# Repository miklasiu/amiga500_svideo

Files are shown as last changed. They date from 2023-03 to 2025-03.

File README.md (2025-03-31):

I've just made it - there are errors :) I'll update sometime when I find the time. Generally it works. Basically red and blue are swapped on the AD724 input (oops) and input resistor divider needs to be adjusted to increase voltage a bit. Also AD724 input resistors need to have larger values to decrease current draw.

# amiga500_svideo
 Luma Chroma output from A500

GGLabs A520HD redraw with AD724 based SVIDEO.

Connector PCB to fit on the right side behind the floppy.

To keep the video port operational I will do high impedance input (not 75 ohm) tap directly to video hybrid circuit and adjust input level via resistor divider. 
The same applies to AD724. It needs 714mVpp so I _think_ it needs 1/2nd of the A500HD output. But we shall see.

Work in progress.

BTW - I just bought my 1st Amiga in 2022. So I am ~30years behind. Catching up. 
Just noticed all mods cost more than A500. It seems cheaper and surely funnier to do them myself.
Fortunately my A500 is broken so more projects coming as original parts are expensive too :D

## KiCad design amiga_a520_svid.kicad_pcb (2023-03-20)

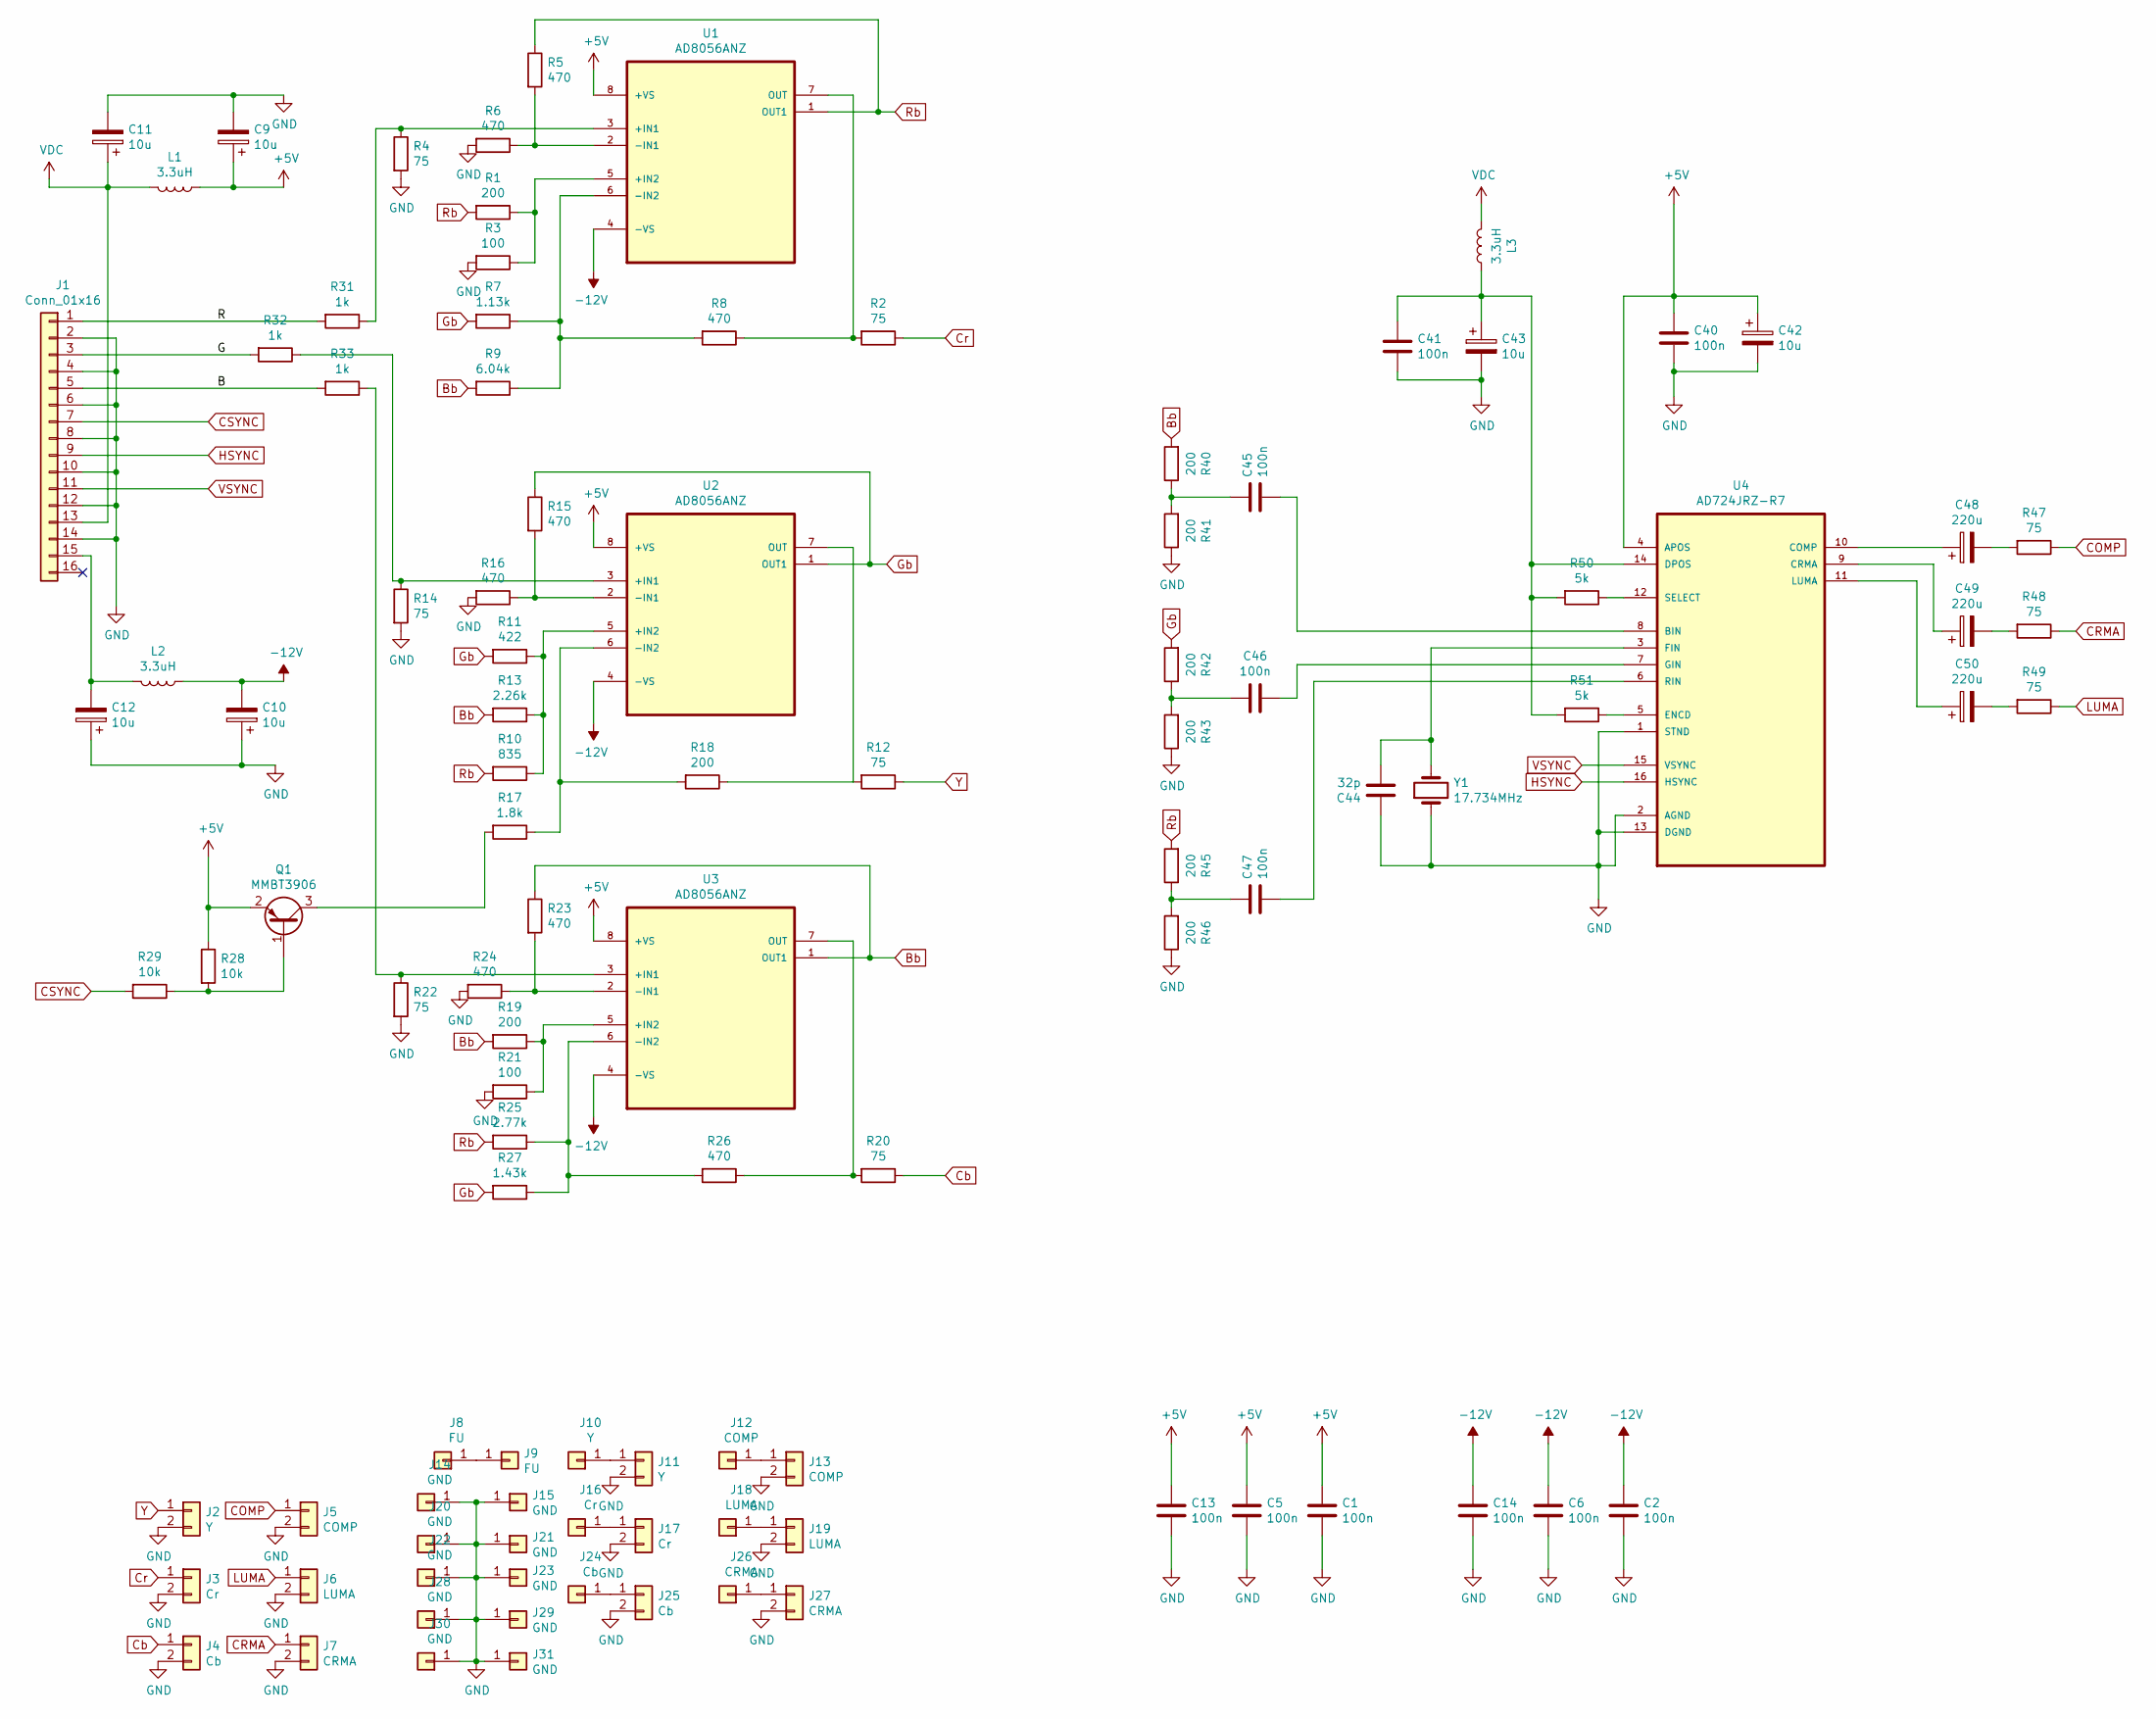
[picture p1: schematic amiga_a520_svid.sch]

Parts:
C1, C2, C5, C6, C13, C14, C40, C41, C45, C46, C47: 100n; C_1206_3216Metric_Pad1.33x1.80mm_HandSolder
C9, C10, C11, C12, C42, C43: 10u; CP_Elec_5x5.4
C44: 32p; C_1206_3216Metric_Pad1.33x1.80mm_HandSolder
C48, C49, C50: 220u; CP_Elec_6.3x7.7
J1: Conn_01x16; PinHeader_1x16_P1.27mm_Vertical_SMD_Pin1Left
J2, J11: Y; PinHeader_1x02_P2.54mm_Vertical
J3, J17: Cr; PinHeader_1x02_P2.54mm_Vertical
J4, J25: Cb; PinHeader_1x02_P2.54mm_Vertical
J5, J13: COMP; PinHeader_1x02_P2.54mm_Vertical
J6, J19: LUMA; PinHeader_1x02_P2.54mm_Vertical
J7, J27: CRMA; PinHeader_1x02_P2.54mm_Vertical
J8, J9: FU; Pin_D0.9mm_L10.0mm_W2.4mm_FlatFork
J10: Y; Pin_D0.9mm_L10.0mm_W2.4mm_FlatFork
J12: COMP; Pin_D0.9mm_L10.0mm_W2.4mm_FlatFork
J14, J15, J20, J21, J22, J23, J28, J29, J30, J31: GND; Pin_D0.9mm_L10.0mm_W2.4mm_FlatFork
J16: Cr; Pin_D0.9mm_L10.0mm_W2.4mm_FlatFork
J18: LUMA; Pin_D0.9mm_L10.0mm_W2.4mm_FlatFork
J24: Cb; Pin_D0.9mm_L10.0mm_W2.4mm_FlatFork
J26: CRMA; Pin_D0.9mm_L10.0mm_W2.4mm_FlatFork
L1, L2, L3: 3.3uH; L_Axial_L7.0mm_D3.3mm_P10.16mm_Horizontal_Fastron_MICC
Q1: MMBT3906; SOT-23
R1, R18, R19, R40, R41, R42, R43, R45, R46: 200; R_1206_3216Metric_Pad1.30x1.75mm_HandSolder
R2, R4, R12, R14, R20, R22, R47, R48, R49: 75; R_1206_3216Metric_Pad1.30x1.75mm_HandSolder
R3, R21: 100; R_1206_3216Metric_Pad1.30x1.75mm_HandSolder
R5, R6, R8, R15, R16, R23, R24, R26: 470; R_1206_3216Metric_Pad1.30x1.75mm_HandSolder
R7: 1.13k; R_1206_3216Metric_Pad1.30x1.75mm_HandSolder
R9: 6.04k; R_1206_3216Metric_Pad1.30x1.75mm_HandSolder
R10: 835; R_1206_3216Metric_Pad1.30x1.75mm_HandSolder
R11: 422; R_1206_3216Metric_Pad1.30x1.75mm_HandSolder
R13: 2.26k; R_1206_3216Metric_Pad1.30x1.75mm_HandSolder
R17: 1.8k; R_1206_3216Metric_Pad1.30x1.75mm_HandSolder
R25: 2.77k; R_1206_3216Metric_Pad1.30x1.75mm_HandSolder
R27: 1.43k; R_1206_3216Metric_Pad1.30x1.75mm_HandSolder
R28, R29: 10k; R_1206_3216Metric_Pad1.30x1.75mm_HandSolder
R31, R32, R33: 1k; R_1206_3216Metric_Pad1.30x1.75mm_HandSolder
R50, R51: 5k; R_1206_3216Metric_Pad1.30x1.75mm_HandSolder
U1, U2, U3: AD8056ANZ; DIP-8_W7.62mm_SOIC-8; MPN AD8056ANZ
U4: AD724JRZ-R7; SOIC-16W_7.5x10.3mm_P1.27mm; MPN AD724JRZ-R7
Y1: 17.734MHz; Resonator-2Pin_W10.0mm_H5.0mm

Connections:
+5V: C1.1, C5.1, C9.1, C13.1, C40.1, C42.1, L1.1, Q1.2 (E), R28.1, U1.8 (+VS), U2.8 (+VS), U3.8 (+VS), U4.4 (APOS)
-12V: C2.1, C6.1, C10.2, C14.1, L2.1, U1.4 (-VS), U2.4 (-VS), U3.4 (-VS)
/B: J1.5, R33.2
/G: J1.3, R32.2
/R: J1.1, R31.2
Bb: R9.2, R13.2, R19.2, R23.1, R40.2, U3.1 (OUT1)
COMP: J5.1, R47.1
CRMA: J7.1, R48.1
CSYNC: J1.7, R29.2
Cb: J4.1, R20.1
Cr: J3.1, R2.1
GND: C1.2, C2.2, C5.2, C6.2, C9.2, C10.1, C11.2, C12.1, C13.2, C14.2, C40.2, C41.2, C42.2, C43.2, C44.1, J1.2, J1.4, J1.6, J1.8, J1.10, J1.12, J1.14, J2.2, J3.2, J4.2, J5.2, J6.2, J7.2, J11.2, J13.2, J14.1, J15.1, J17.2, J19.2, J20.1, J21.1, J22.1, J23.1, J25.2, J27.2, J28.1, J29.1, J30.1, J31.1, R3.2, R4.2, R6.2, R14.2, R16.2, R21.2, R22.2, R24.2, R41.1, R43.1, R46.1, U4.1 (STND), U4.2 (AGND), U4.13 (DGND), Y1.1
Gb: R7.2, R11.2, R15.1, R27.2, R42.2, U2.1 (OUT1)
HSYNC: J1.9, U4.16 (HSYNC)
LUMA: J6.1, R49.1
unnamed: C12.2, J1.15, L2.2
unnamed: C41.1, C43.1, L3.1, R50.2, R51.2, U4.14 (DPOS)
unnamed: C44.2, U4.3 (FIN), Y1.2
unnamed: C45.1, R40.1, R41.2
unnamed: C45.2, U4.8 (BIN)
unnamed: C46.1, R42.1, R43.2
unnamed: C46.2, U4.7 (GIN)
unnamed: C47.1, R45.1, R46.2
unnamed: C47.2, U4.6 (RIN)
unnamed: C48.1, U4.10 (COMP)
unnamed: C48.2, R47.2
unnamed: C49.1, U4.9 (CRMA)
unnamed: C49.2, R48.2
unnamed: C50.1, U4.11 (LUMA)
unnamed: C50.2, R49.2
unnamed: J8.1, J9.1
unnamed: J10.1, J11.1
unnamed: J12.1, J13.1
unnamed: J16.1, J17.1
unnamed: J18.1, J19.1
unnamed: J24.1, J25.1
unnamed: J26.1, J27.1
unnamed: Q1.1 (B), R28.2, R29.1
unnamed: Q1.3 (C), R17.2
unnamed: R1.1, R3.1, U1.5 (+IN2)
unnamed: R2.2, R8.1, U1.7 (OUT)
unnamed: R5.2, R6.1, U1.2 (-IN1)
unnamed: R7.1, R8.2, R9.1, U1.6 (-IN2)
unnamed: R10.1, R11.1, R13.1, U2.5 (+IN2)
unnamed: R12.2, R18.1, U2.7 (OUT)
unnamed: R14.1, R32.1, U2.3 (+IN1)
unnamed: R15.2, R16.1, U2.2 (-IN1)
unnamed: R17.1, R18.2, U2.6 (-IN2)
unnamed: R19.1, R21.1, U3.5 (+IN2)
unnamed: R20.2, R26.1, U3.7 (OUT)
unnamed: R22.1, R33.1, U3.3 (+IN1)
unnamed: R23.2, R24.1, U3.2 (-IN1)
unnamed: R25.1, R26.2, R27.1, U3.6 (-IN2)
unnamed: R4.1, R31.1, U1.3 (+IN1)
unnamed: R50.1, U4.12 (SELECT)
unnamed: R51.1, U4.5 (ENCD)
Rb: R1.2, R5.1, R10.2, R25.2, R45.2, U1.1 (OUT1)
VDC: C11.1, J1.13, L1.2, L3.2
VSYNC: J1.11, U4.15 (VSYNC)
Y: J2.1, R12.1

Board: 2 copper layers, 104 parts (6 on the bottom side), 60 nets, no tracks yet.

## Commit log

2023-02-13 Wider tracks.
    Reroute using wider tracks to help with manual board manufacturing. SVG for printing on transfer material. Mirror F_*
    [amiga_a520_svid.kicad_pcb]
2023-03-20 Fixes after 1st prototype :)
    - Swapped OPAMP outputs :(
    - More careful AD724 implementation
    - MORE SMD! Through hole without metallization is a pain!
    [amiga_a520_svid.kicad_pcb, amiga_a520_svid.sch]
